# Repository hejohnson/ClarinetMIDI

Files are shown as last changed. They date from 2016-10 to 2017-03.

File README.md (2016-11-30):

# ClarinetMIDI

This repository contains the code to run a Clarinet MIDI controller. The hardware is based on a Teensy 2.0 MCU, wired to two MPR121 capacitive touch breakout boards from Adafruit. Each pad on the breakout is wired to a fingerpad (I used washers hot-glued to the PVC body). Breath is sensed with a MXP5010 air pressure sensor. 

The notes are contained in a lookup table, as a MIDI note number and an array of keys that are pressed for that note. After the note is looked up, it is shifted two octaves due to how computers interpret the MIDI notes.

All of the parts totaled approximately $100:
1x Teensy 2.0 (could probably use other Teensys, but the 2.0 is the cheapest)  
2x MPR 121  
1x MXP 5010  
17 1" fender washers (keys)  
17 #4 sheet metal screws (secure mounting of keys)  
2' length of 1-1/2 PVC pipe  
2x 1-1/2 PVC end caps  
1x 2' of 1/4" ID Vinyl tubing for connecting mouthpiece to sensor. Poke a hole to let the air out  
1x USB Female USB-B to Male microUSB (optional, makes the cable detachable)  
1x 10' USB Male A-B cable  
Laser cut plywood internal assembly (super-duper fancy shmancy)  
2.5" feet of 28 AWG (17 strands wide) for hooking up pads  
Hot glue/wire/solder/0.1" header pins and crimps/etc for connecting everything

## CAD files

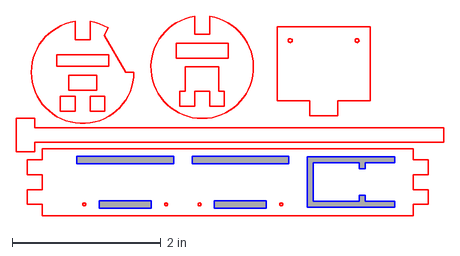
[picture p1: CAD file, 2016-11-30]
ClarinetCuts.dxf
5.75 x 2.68 in

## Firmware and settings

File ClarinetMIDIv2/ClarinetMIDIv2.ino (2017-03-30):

#include <Wire.h>
#include "Adafruit_MPR121.h"

#define NUM_NOTES 43
#define BREATHSENSEPIN 10

#define BREATHRESTING_CUTOFF 55
#define BREATHMAX 512

//#define USESERIAL

Adafruit_MPR121 buttons1 = Adafruit_MPR121();
Adafruit_MPR121 buttons2 = Adafruit_MPR121();

// Keeps track of the last pins touched
// so we know when buttons are 'released'
uint16_t currTouched_buttons1 = 0;
uint16_t currTouched_buttons2 = 0;

uint32_t currTouched = 0;

uint8_t currentMIDINote = 0;
uint8_t newMIDINote = 0;

bool noteOffSent = false;

typedef struct {
  uint8_t midiNote;
  //uint8_t numberKeys
  int8_t keys[9];
} note_t;

// the MIDI channel number to send messages
const int channel = 1;

uint32_t genKeyMask(int8_t* key) {
  uint32_t blankMask = 0;
  for (int i = 0; i<9; i++) {
    if (key[i] == -1) {
      continue;
    } else {
      blankMask |= (1L<<key[i]);
    }
  }
  return blankMask;
}

note_t noteLookupTable[NUM_NOTES] = {
  {26,{16,2,3,4,8,9,10,13,-1}},
  {27,{16,2,3,4,8,9,10,14,-1}},
  {28,{16,2,3,4,8,9,10,11,-1}},
  {29,{16,2,3,4,8,9,10,-1,-1}},
  {30,{16,2,3,4,8,9,10,12,-1}},
  {31,{16,2,3,4,8,9,-1,-1,-1}},
  {32,{16,2,3,4,8,-1,-1,-1,-1}},
  {33,{16,2,3,4,9,-1,-1,-1,-1}},
  {34,{16,2,3,4,-1,-1,-1,-1,-1}},
  {35,{16,2,3,4,5,-1,-1,-1,-1}},
  {36,{16,2,3,-1,-1,-1,-1,-1,-1}},
  {37,{16,2,3,6,-1,-1,-1,-1,-1}},
  {38,{16,2,-1,-1,-1,-1,-1,-1,-1}},
  {39,{16,-1,-1,-1,-1,-1,-1,-1,-1}},
  {40,{2,-1,-1,-1,-1,-1,-1,-1,-1}},
  {41,{-1,-1,-1,-1,-1,-1,-1,-1,-1}},
  {42,{1,-1,-1,-1,-1,-1,-1,-1,-1}},
  {43,{0,-1,-1,-1,-1,-1,-1,-1,-1}},
  {44,{15,0,-1,-1,-1,-1,-1,-1,-1}},
  {45,{15,16,2,3,4,8,9,10,13}},
  {46,{15,16,2,3,4,8,9,10,14}},
  {46,{15,16,2,3,4,7,8,9,10}},
  {47,{15,16,2,3,4,8,9,10,11}},
  {48,{15,16,2,3,4,8,9,10,-1}},
  {49,{15,16,2,3,4,8,9,10,12}},
  {50,{15,16,2,3,4,8,9,-1,-1}},
  {51,{15,16,2,3,4,8,-1,-1,-1}},
  {52,{15,16,2,3,4,9,-1,-1,-1}},
  {53,{15,16,2,3,4,-1,-1,-1,-1}},
  {54,{15,16,2,3,4,5,-1,-1,-1}},
  {55,{15,16,2,3,-1,-1,-1,-1,-1}},
  {56,{15,16,2,3,6,-1,-1,-1,-1}},
  {57,{15,16,2,-1,-1,-1,-1,-1,-1}},
  {58,{15,16,-1,-1,-1,-1,-1,-1,-1}},
  {59,{15,16,3,4,8,9,-1,-1,-1}},
  {60,{15,16,3,4,8,12,-1,-1,-1}},
  {61,{15,16,3,4,9,12,-1,-1,-1}},
  {62,{15,16,3,4,12,-1,-1,-1,-1}},
  {63,{15,16,3,4,5,12,-1,-1,-1}},
  {64,{15,16,3,12,-1,-1,-1,-1,-1}},
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
};

void setup() {
  #ifdef USESERIAL
  Serial.begin(9600);
  #endif

  if(!buttons1.begin(0x5A)) {
    #ifdef USESERIAL
    Serial.println("0x5A Failed to init");
    #endif
  }

  if (!buttons2.begin(0x5B)) {
    #ifdef USESERIAL
    Serial.println("0x5B Failed to init");
    #endif
  }

}

void loop() {
  currTouched_buttons1 = buttons1.touched();
  currTouched_buttons2 = buttons2.touched();

  currTouched = (uint32_t)currTouched_buttons1 + ((uint32_t)currTouched_buttons2 << 12);
  
  if (analogRead(BREATHSENSEPIN) < BREATHRESTING_CUTOFF) {
    if (!noteOffSent) {
      usbMIDI.sendNoteOff(currentMIDINote, 0, channel); // if you're not blowing, stop sending the note
      noteOffSent = true;
    }
  } else {
      for (int i = 0; i < NUM_NOTES; i++) {
        uint32_t keyMask = genKeyMask(noteLookupTable[i].keys);
        if (currTouched == keyMask) { // Does the current index match an actual note?
          newMIDINote = noteLookupTable[i].midiNote+24; // figure out the matching MIDI note ID

          if (newMIDINote != currentMIDINote || noteOffSent) { // If its a different note, stop sending the current note and send the new one
            noteOffSent = false;
            if (newMIDINote != currentMIDINote) {
              usbMIDI.sendNoteOff(currentMIDINote, 0, channel); // stop sending the last note
            }
            currentMIDINote = newMIDINote;
            usbMIDI.sendNoteOn(currentMIDINote, constrain(map(analogRead(BREATHSENSEPIN), BREATHRESTING_CUTOFF, BREATHMAX-25, 0, 99), 15, 99), channel); // send the new note
          }
          break; // stop looking for notes
        }
      }
  }

  // MIDI Controllers should discard incoming MIDI messages.
  // http://forum.pjrc.com/threads/24179-Teensy-3-Ableton-Analog-CC-causes-midi-crash
  while (usbMIDI.read()) {
    // ignore incoming messages
  }
  delay(50);
}

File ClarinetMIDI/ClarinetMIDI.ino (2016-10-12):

#include <Wire.h>
#include "Adafruit_MPR121.h"

#define NUM_NOTES 42
#define BREATHSENSEPIN 10

//#define USESERIAL

Adafruit_MPR121 buttons1 = Adafruit_MPR121();
Adafruit_MPR121 buttons2 = Adafruit_MPR121();

// Keeps track of the last pins touched
// so we know when buttons are 'released'
uint16_t currTouched_buttons1 = 0;
uint16_t currTouched_buttons2 = 0;

uint32_t lastTouched = 0;
uint32_t currTouched = 0;

uint8_t currentMIDINote = 0;
uint8_t newMIDINote = 0;

union {
  struct {
    uint32_t padding:15;
    uint8_t pad17:1;
    uint8_t pad16:1;
    uint8_t pad15:1;
    uint8_t pad14:1;
    uint8_t pad13:1;
    uint8_t pad12:1;
    uint8_t pad11:1;
    uint8_t pad10:1;
    uint8_t pad9:1;
    uint8_t pad8:1;
    uint8_t pad7:1;
    uint8_t pad6:1;
    uint8_t pad5:1;
    uint8_t pad4:1;
    uint8_t pad3:1;
    uint8_t pad2:1;
    uint8_t pad1:1;  
  }
}

typedef struct {
  uint8_t midiNote;
  uint32_t keyMask;
} note_t;

// the MIDI channel number to send messages
const int channel = 1;

note_t noteLookupTable[NUM_NOTES] = {
  {58, 0b00000000000000010000000000011100}, // A#2
  {70, 0b00000000000000011100011100011100}, // A#3
  {82, 0b00000000000000011000000000000000}, // A#4
  {57, 0b00000000000000010000001000011100}, // A2
  {69, 0b00000000000000011010011100011100}, // A3
  {81, 0b00000000000000011000000000000100}, // A4
  {93, 0b00000000000000010000000000111100}, // B2
  {71, 0b00000000000000011000111100011100}, // B3
  {83, 0b00000000000000011000001100001100}, // B4
  {61, 0b00000000000000010000000001001100}, // C#3
  {73, 0b00000000000000011000101110011100}, // C#4
  {85, 0b00000000000000011000000000011000}, // C#5
  {60, 0b00000000000000010000000000001100}, // C3
  {72, 0b00000000000000011000011100011100}, // C4
  {84, 0b00000000000000011001000100011000}, // C5
  {51, 0b00000000000000010100011100011100}, // D#2
  {63, 0b00000000000000010000000000000000}, // D#3
  {75, 0b00000000000000011000000010011100}, // D#4
  {87, 0b00000000000000011001000000111000}, // D#5
  {50, 0b00000000000000010010011100011100}, // D2
  {62, 0b00000000000000010000000000000100}, // D3
  {74, 0b00000000000000011000001100011100}, // D4
  {86, 0b00000000000000011000100000011000}, // D5
  {52, 0b00000000000000010000111100011100}, // E2
  {64, 0b00000000000000000000000000000100}, // E3
  {76, 0b00000000000000011000001000011100}, // E4
  {88, 0b00000000000000011001000000001000}, // E5
  {54, 0b00000000000000010001011100011100}, // F#2
  {66, 0b00000000000000000000000000000010}, // F#3
  {78, 0b00000000000000011000000000111100}, // F#4
  {90, 0b00000000000000011001000100000000}, // F#5
  {53, 0b00000000000000010000011100011100}, // F2
  {65, 0b00000000000000000000000000000000}, // F3
  {77, 0b00000000000000011000000000011100}, // F4
  {89, 0b00000000000000011001001100010000}, // F5
  {56, 0b00000000000000010000000100011100}, // G#2
  {68, 0b00000000000000001000000000000001}, // G#3
  {80, 0b00000000000000011000000001001100}, // G#4
  {55, 0b00000000000000010000001100011100}, // G2
  {67, 0b00000000000000000000000000000001}, // G3
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
};

void setup() {
  #ifdef USESERIAL
  Serial.begin(9600);
  #endif

  if(!buttons1.begin(0x5A)) {
    #ifdef USESERIAL
    Serial.println("0x5A Failed to init");
    #endif
  }

  if (!buttons2.begin(0x5B)) {
    #ifdef USESERIAL
    Serial.println("0x5B Failed to init");
    #endif
  }

  #ifdef USESERIAL
  Serial.println("startup successful");
  #endif
}

void loop() {
  currTouched_buttons1 = buttons1.touched();
  currTouched_buttons2 = buttons2.touched();

  currTouched = (uint32_t)currTouched_buttons1 + ((uint32_t)currTouched_buttons2 << 12);
  
  if (analogRead(BREATHSENSEPIN) < 100) {
    #ifndef USESERIAL
    usbMIDI.sendNoteOff(currentMIDINote, 0, channel); // if you're not blowing, stop sending the note
    #endif
    currentMIDINote = 0;
  } else {
//    if (lastTouched != currTouched) {
//      #ifdef USESERIAL
//      Serial.println(currTouched, BIN);
//      #endif
      for (int i = 0; i < NUM_NOTES; i++) {
        if (currTouched == noteLookupTable[i].keyMask) { // Does the current index match an actual note?
          #ifdef USESERIAL
          Serial.print(currentMIDINote);
          Serial.println(" off");
          #else

          newMIDINote = noteLookupTable[i].midiNote; // figure out the matching MIDI note ID

          if (newMIDINote != currentMIDINote) { // If its a different note, stop sending the current note and send the new one
            usbMIDI.sendNoteOff(currentMIDINote, 0, channel); // stop sending the last note
            #endif
            currentMIDINote = newMIDINote;
            #ifdef USESERIAL
            Serial.print(currentMIDINote);
            Serial.println(" on");
            #else
            usbMIDI.sendNoteOn(currentMIDINote, 99, channel); // send the new note
            #endif
          }
          break; // stop looking for notes
        }
      }
      // reset our state
     // lastTouched = currTouched;
//    } else {
//      #ifndef USESERIAL
//      usbMIDI.sendNoteOff(currentMIDINote, 0, channel); //#TODO: not an actual note, not sending anything for now, but not sure if that's the desired behavior
//      #endif
//    }
  }

  // MIDI Controllers should discard incoming MIDI messages.
  // http://forum.pjrc.com/threads/24179-Teensy-3-Ableton-Analog-CC-causes-midi-crash
  #ifndef USESERIAL
  while (usbMIDI.read()) {
    // ignore incoming messages
  }
  #endif
  delay(50);
}

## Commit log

2016-11-30 Fixed bitmask creation, added modified MPR121 library for autocalibration of thresholds
    [ClarinetMIDIv2.ino]
2016-11-30 Added DXF for internal structure
    [ClarinetCuts.dxf]
2016-12-01 Cleaned up debugging code and maxed charge current
2017-03-22 Added breath sensor calibration
2017-03-29 Updated scaling with actual device values
